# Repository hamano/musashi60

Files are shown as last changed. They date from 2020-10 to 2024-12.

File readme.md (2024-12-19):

# Musashi60 - Open Hardware Keyboard

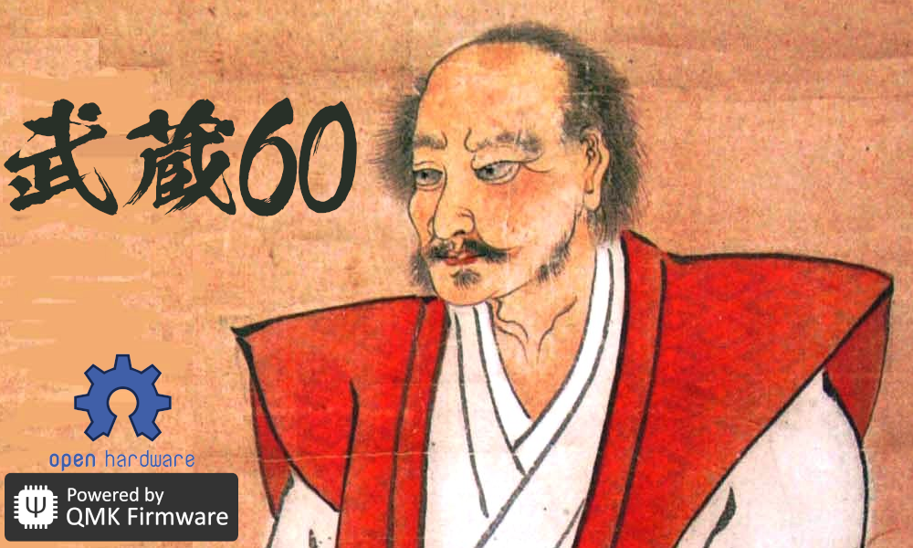
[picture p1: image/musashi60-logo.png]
musashi60-logo


## Overview

Musashi60 is open-hardware splitted keyboard.

* Keys: 60
* Layout: Ergonomic column-staggered
* All parts are available to procured or make yourself. see [parts](#parts-list).
* Keyboard Maintainer: [HAMANO Tsukasa](https://github.com/hamano)
* Hardware Supported: The PCBs, controllers supported
* Hardware Availability: Links to where you can find this hardware

Make example for this keyboard (after setting up your build environment):

    make musashi60:default

See the [build environment setup](https://docs.qmk.fm/#/getting_started_build_tools) and the [make instructions](https://docs.qmk.fm/#/getting_started_make_guide) for more information. Brand new to QMK? Start with our [Complete Newbs Guide](https://docs.qmk.fm/#/newbs).

## Gallery

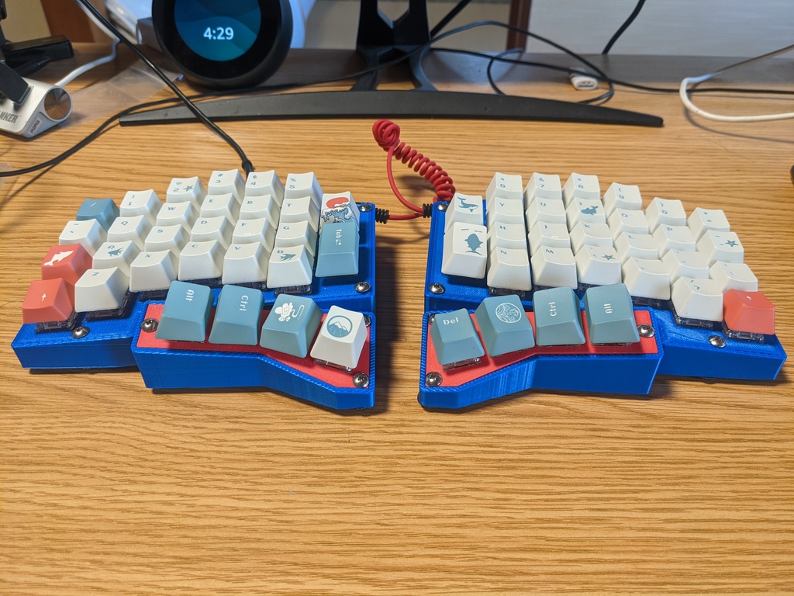
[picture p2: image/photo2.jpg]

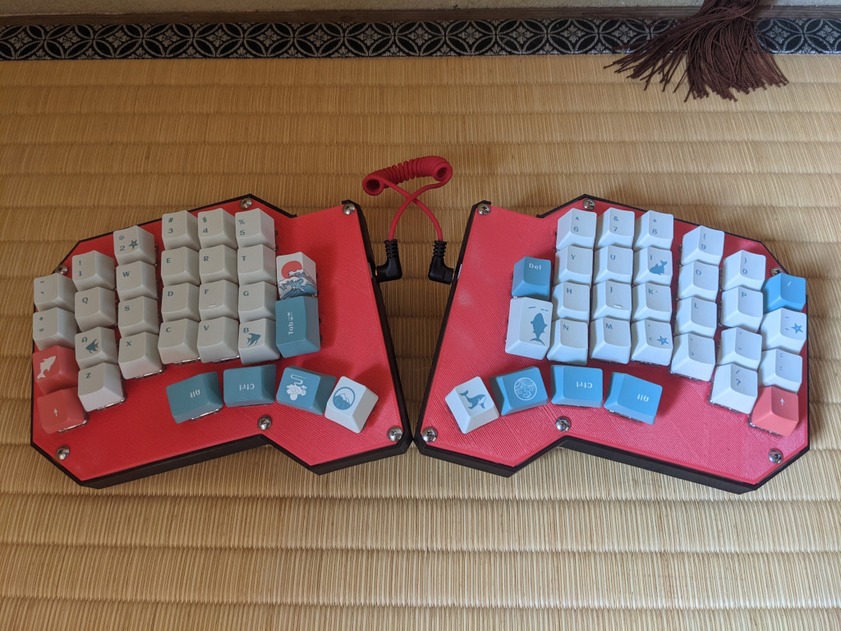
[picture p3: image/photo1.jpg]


## Parts list

- RP2024
- PCB
- case
- plate
- screw

## Build guide

Comming soon...

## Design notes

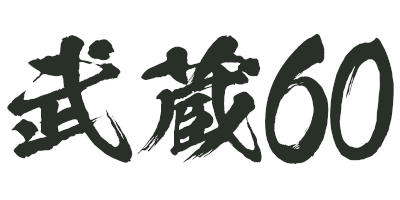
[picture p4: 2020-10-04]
image/musashi60-silk.png

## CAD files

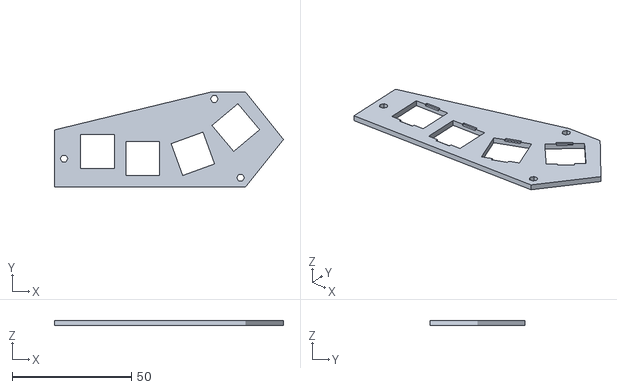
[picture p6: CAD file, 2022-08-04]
case/revG/thumb_plate.stl
96.0 x 40.0 x 2.00

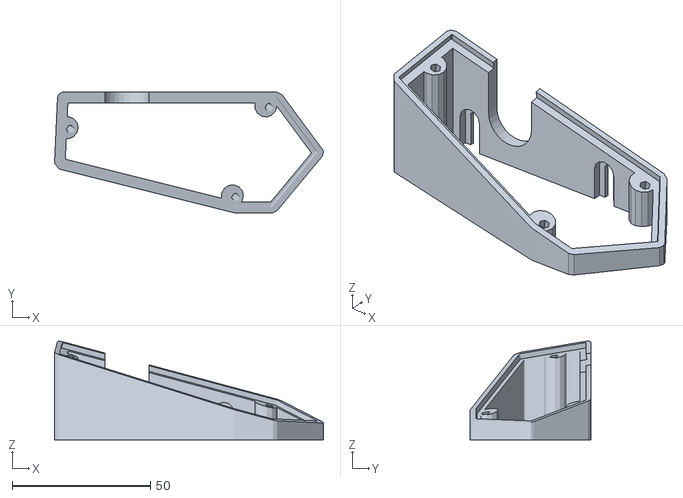
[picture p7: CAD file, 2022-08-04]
case/revG/thumb_case.stl
97.3 x 43.7 x 35.8

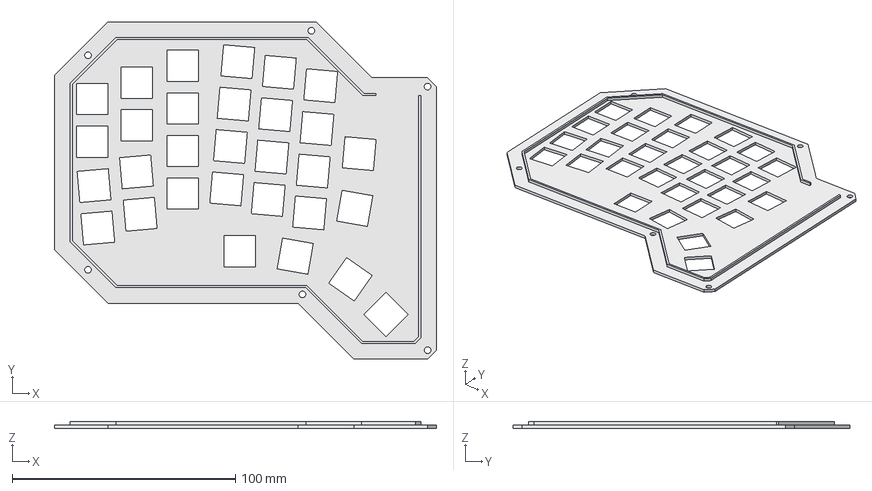
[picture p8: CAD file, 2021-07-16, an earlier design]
case/revC/revC.FCStd
171.0 x 151.0 x 3.00 mm

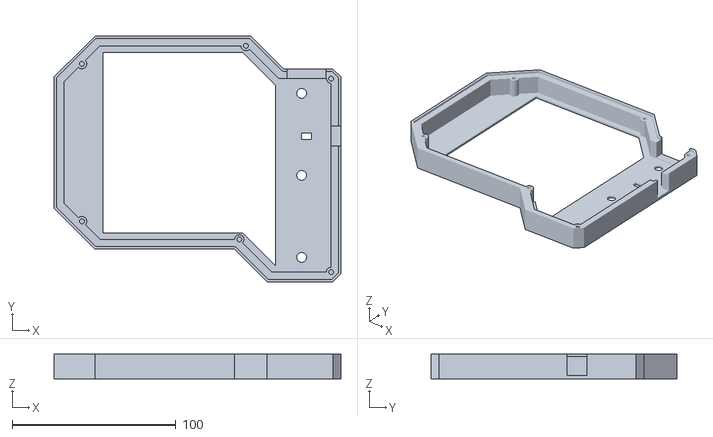
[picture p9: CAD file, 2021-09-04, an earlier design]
case/revD/revD-case5.stl
175.0 x 150.0 x 15.0

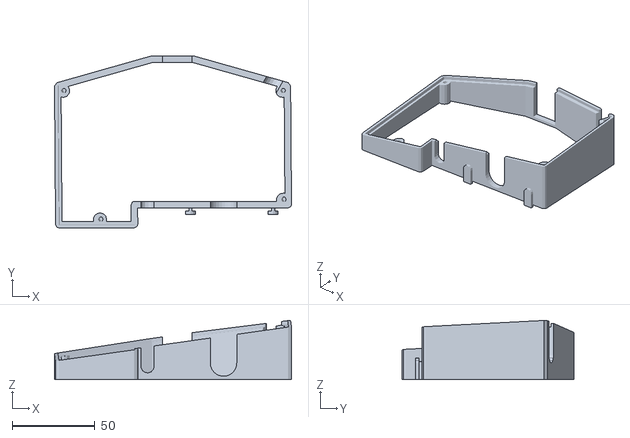
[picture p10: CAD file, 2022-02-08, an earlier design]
case/revE/finger_case.stl
143.4 x 104.0 x 35.8

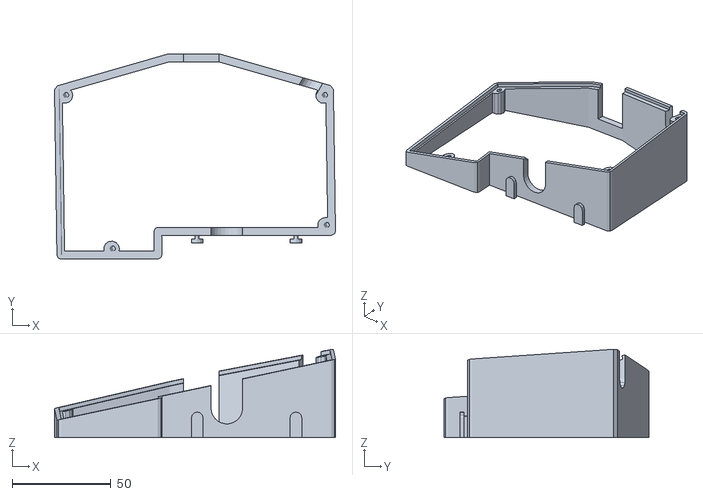
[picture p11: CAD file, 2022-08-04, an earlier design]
case/revF/finger_case.stl
142.3 x 103.9 x 44.8

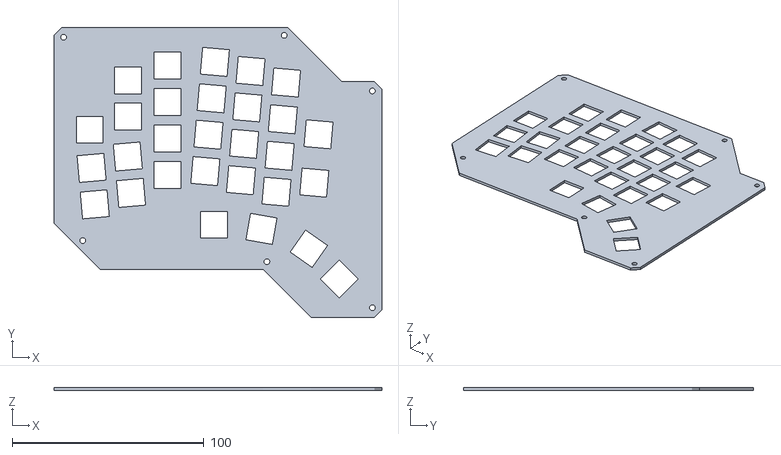
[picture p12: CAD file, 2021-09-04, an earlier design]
case/revB/revB-plate5.stl
171.0 x 151.0 x 1.50

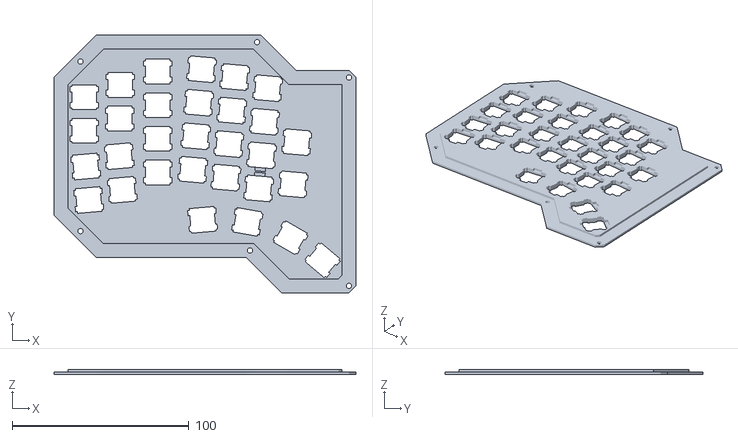
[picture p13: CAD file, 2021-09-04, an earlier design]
case/revD/revD-plate7.stl
171.0 x 146.0 x 3.00

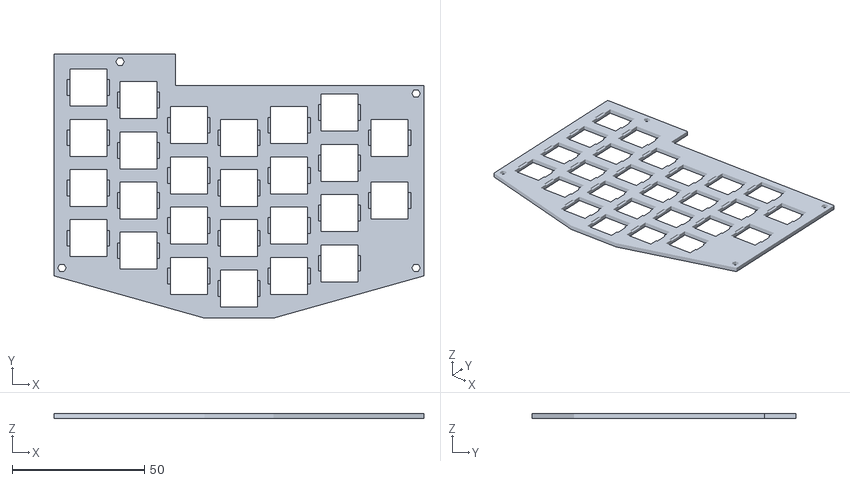
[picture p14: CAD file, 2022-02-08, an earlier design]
case/revE/finger_plate.stl
140.0 x 100.0 x 2.00

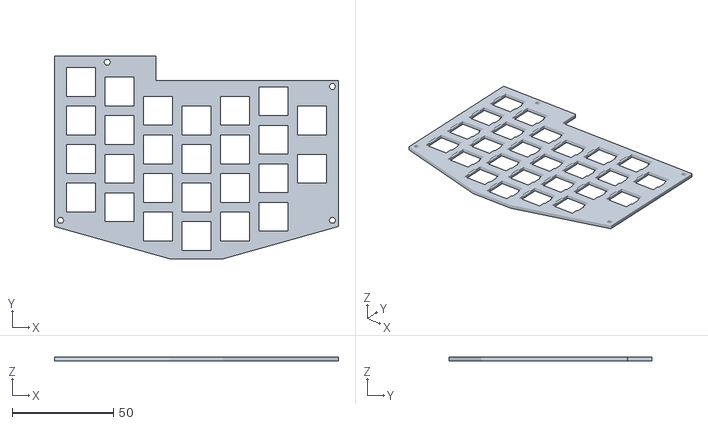
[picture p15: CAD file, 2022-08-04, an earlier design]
case/revF/finger_plate.stl
140.0 x 100.0 x 2.00

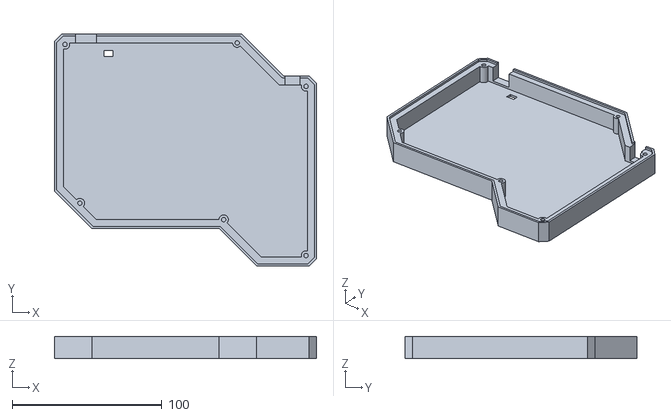
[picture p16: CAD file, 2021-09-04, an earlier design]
case/revB/revB-case-v7.stl
175.0 x 155.0 x 15.0

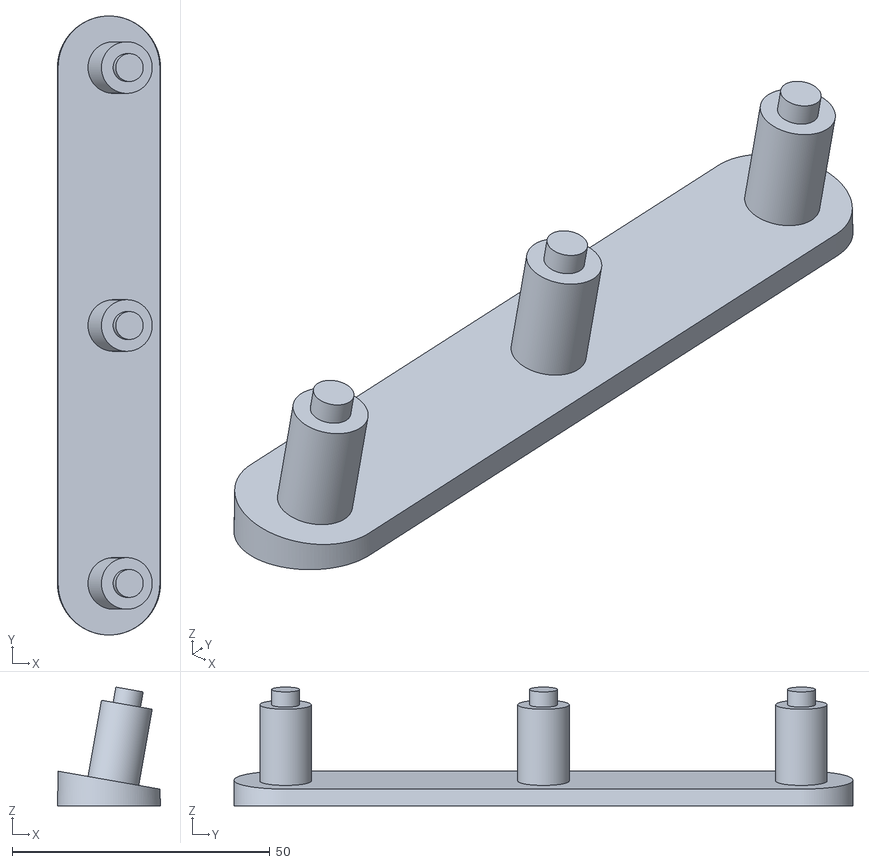
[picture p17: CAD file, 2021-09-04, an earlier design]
case/revD/revD-tilt5.stl
20.0 x 120.0 x 23.0

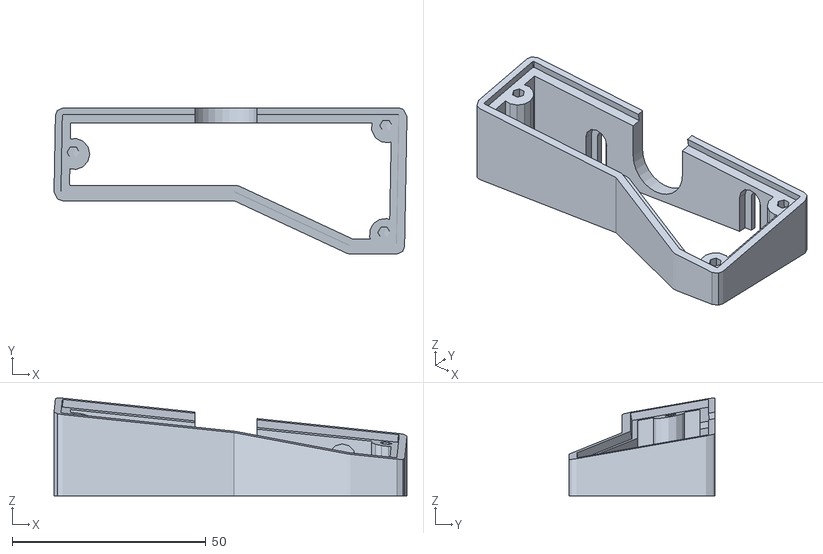
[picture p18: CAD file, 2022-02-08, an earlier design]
case/revE/thumb_case.stl
91.1 x 37.8 x 25.2

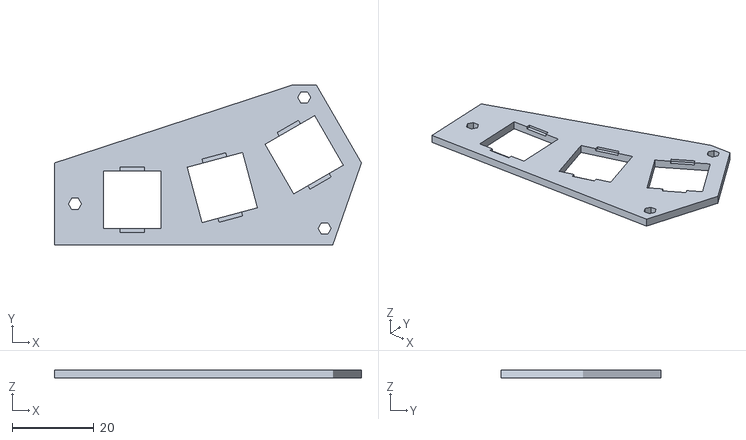
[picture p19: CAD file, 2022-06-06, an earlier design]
case/revF/thumb_plate.stl
75.0 x 39.0 x 2.00

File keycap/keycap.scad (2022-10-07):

cls = 0.2;

module cap_outer() {
    //linear_extrude(height=8, scale=0.7) {
    linear_extrude(height=8, scale=0.7) {
        offset(2, $fs=0.1) {
            square([15,15], center=true);
        }
    }
}

module cap_hole() {
    linear_extrude(height=5, scale=0.7) {
        offset(0, $fs=0.1) {
            square([15,15], center=true);
        }
    }
}

module stem_pole() {
    cylinder(d = 6, h = 10);
}

module stem_hole() {
    linear_extrude(height = 10) {
        square([1+cls, 3.8+cls], center=true);
        square([3.8+cls, 1+cls], center=true);
    }
}

module stem() {
    intersection() {
        cap_outer();
        difference() {
            stem_pole();
            stem_hole();
        };
    }
}

module cap() {
    difference() {
        cap_outer();
        cap_hole();
    }
}


module keycap() {
    cap();
    stem();
}

//cap_outer();

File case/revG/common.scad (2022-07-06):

cls = 0.20;

module keyswitch_hole(x=0, y=0, a=0) {
    translate([x, y, 0]) {
        rotate([0, 0, 90+a]) {
            linear_extrude(height = 2) {
            square([14+cls, 14+cls], center = true);
            }
            linear_extrude(height = 0.6) {
                translate([-3, 7]) square([6, 1]);
            translate([-3, -8]) square([6, 1]);
            }
        }
    }
}

keyswitch_hole();

module joint_male_face() {
    translate([-1, 0])
    square([2,4]);
    translate([-3, 2])
    square([6,2]);
}

module joint_male(pos=[0,0]) {
    translate(pos){
      rotate([0,0,180]){
        linear_extrude(height=10)
        joint_male_face();
        
        translate([0,2,10])
        rotate([-90,0,0])
        linear_extrude(height=2)
        circle(3, $fn=12);
        
        translate([0,0,10])
        rotate([-90,0,0])
        linear_extrude(height=2)
        circle(1, $fn=12);
      }
    }
}

module joint_female(pos=[0,0]) {
    delta = 0.6;
    translate(pos){
      rotate([0,0,180]){
        linear_extrude(height=10)
        offset(delta=delta)
        joint_male_face();
        
        translate([0,1.6,10])
        rotate([-90,0,0])
        linear_extrude(height=2.8)
        offset(delta=delta)
        circle(3, $fn=12);

        translate([0,-0.4,10])
        rotate([-90,0,0])
        linear_extrude(height=2.8)
        offset(delta=delta)
        circle(1, $fn=12);
      }
    }
}


joint_male([20, 0]);
joint_female([30, 0]);

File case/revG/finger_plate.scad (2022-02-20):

use <finger.scad>;

translate([0,-10])
rotate([180,0,0])
finger_plate();

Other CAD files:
case/revB/revB-plate.FCStd
case/revB/revB-hexbottom.FCStd
case/revD/revD.FCStd
case/revE/thumb_plate.stl
case/revG/main.scad
case/revB/revB-case-v6.stl
case/revB/revB-plate.dxf
case/revB/revB.FCStd
case/revE/common.scad
case/revE/finger.scad
case/revE/thumb.scad
case/revF/finger.scad
case/revF/thumb_case.stl
case/revG/main_case.scad
case/revG/main_plate.scad
case/revG/thumb.scad
case/revG/thumb_case.scad
case/revG/thumb_plate.scad
case/revG/unit_case.scad

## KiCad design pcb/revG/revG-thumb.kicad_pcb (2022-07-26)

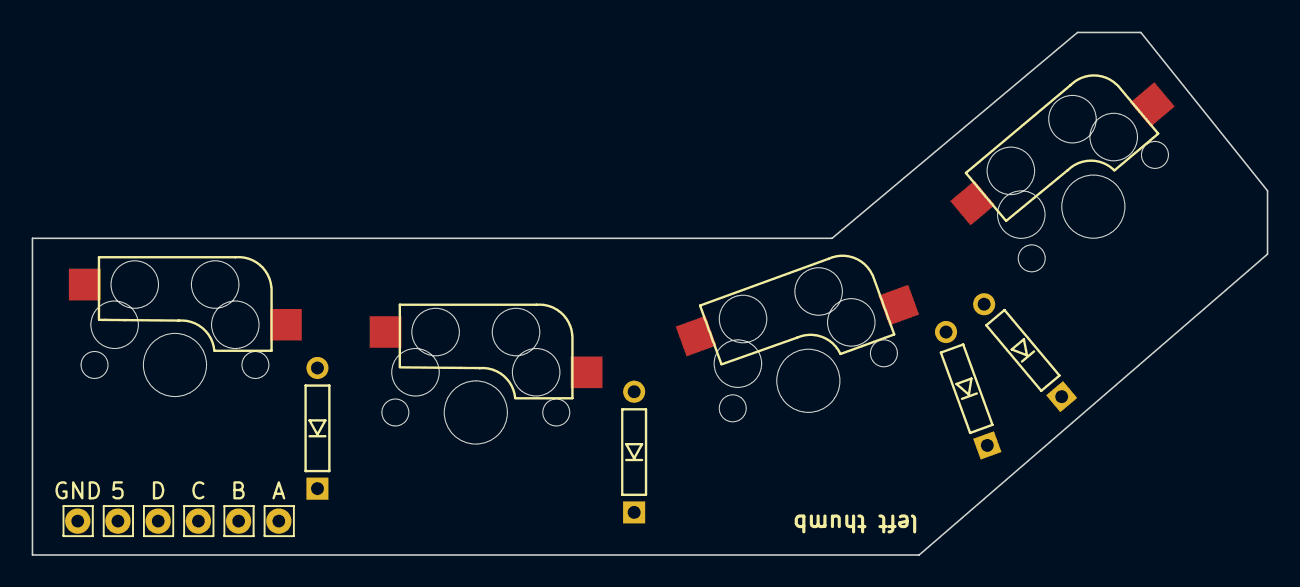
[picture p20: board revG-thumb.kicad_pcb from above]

Board: 2 copper layers, 78.0 x 33.0 mm, 14 parts (0 on the bottom side), 9 nets, no tracks yet.

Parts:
D_LA5: D_A5; D_TH_Reversible
D_LB5: D_B5; D_TH_Reversible
D_LC5: D_C5; D_TH_Reversible
D_LD5: D_D5; D_TH_Reversible
H_L5: 5; Pin_D0.8mm
H_LA1: A; Pin_D0.8mm
H_LB1: B; Pin_D0.8mm
H_LC1: C; Pin_D0.8mm
H_LD5: D; Pin_D0.8mm
H_LGND1: GND; Pin_D0.8mm
SW_LA5: SW_PUSH-foostan; CherryMX_Hotswap_Reversible
SW_LB5: SW_PUSH-foostan; CherryMX_Hotswap_Reversible
SW_LC5: SW_PUSH-foostan; CherryMX_Hotswap_Reversible
SW_LD5: SW_PUSH-foostan; CherryMX_Hotswap_Reversible

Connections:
unnamed: D_LA5.1, D_LB5.1, D_LC5.1, D_LD5.1, H_L5.1
unnamed: D_LA5.2, SW_LA5.1
unnamed: D_LB5.2, SW_LB5.1
unnamed: D_LC5.2, SW_LC5.1
unnamed: D_LD5.2, SW_LD5.1
unnamed: H_LA1.1, SW_LA5.2
unnamed: H_LB1.1, SW_LB5.2
unnamed: H_LC1.1, SW_LC5.2
unnamed: H_LD5.1, SW_LD5.2

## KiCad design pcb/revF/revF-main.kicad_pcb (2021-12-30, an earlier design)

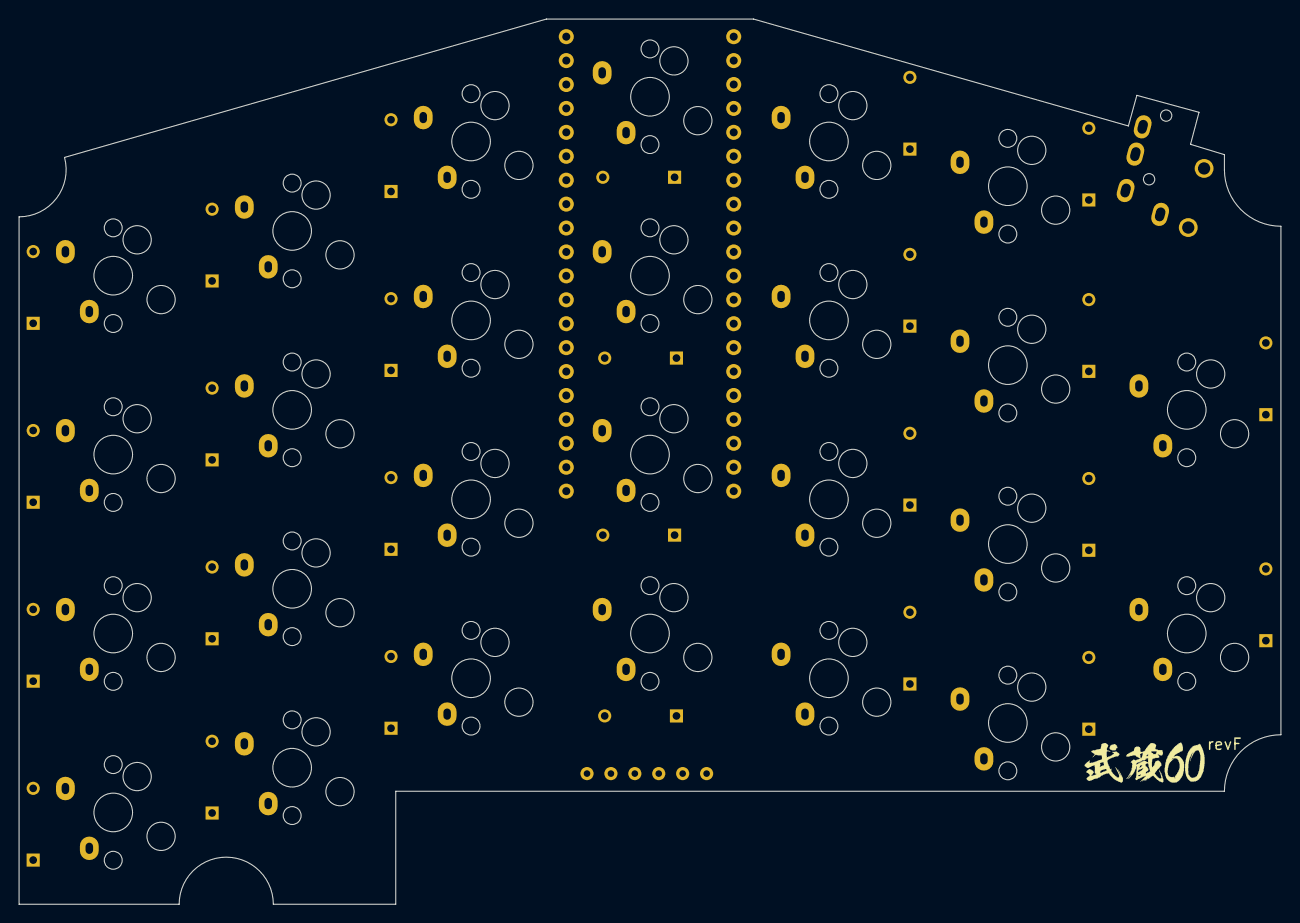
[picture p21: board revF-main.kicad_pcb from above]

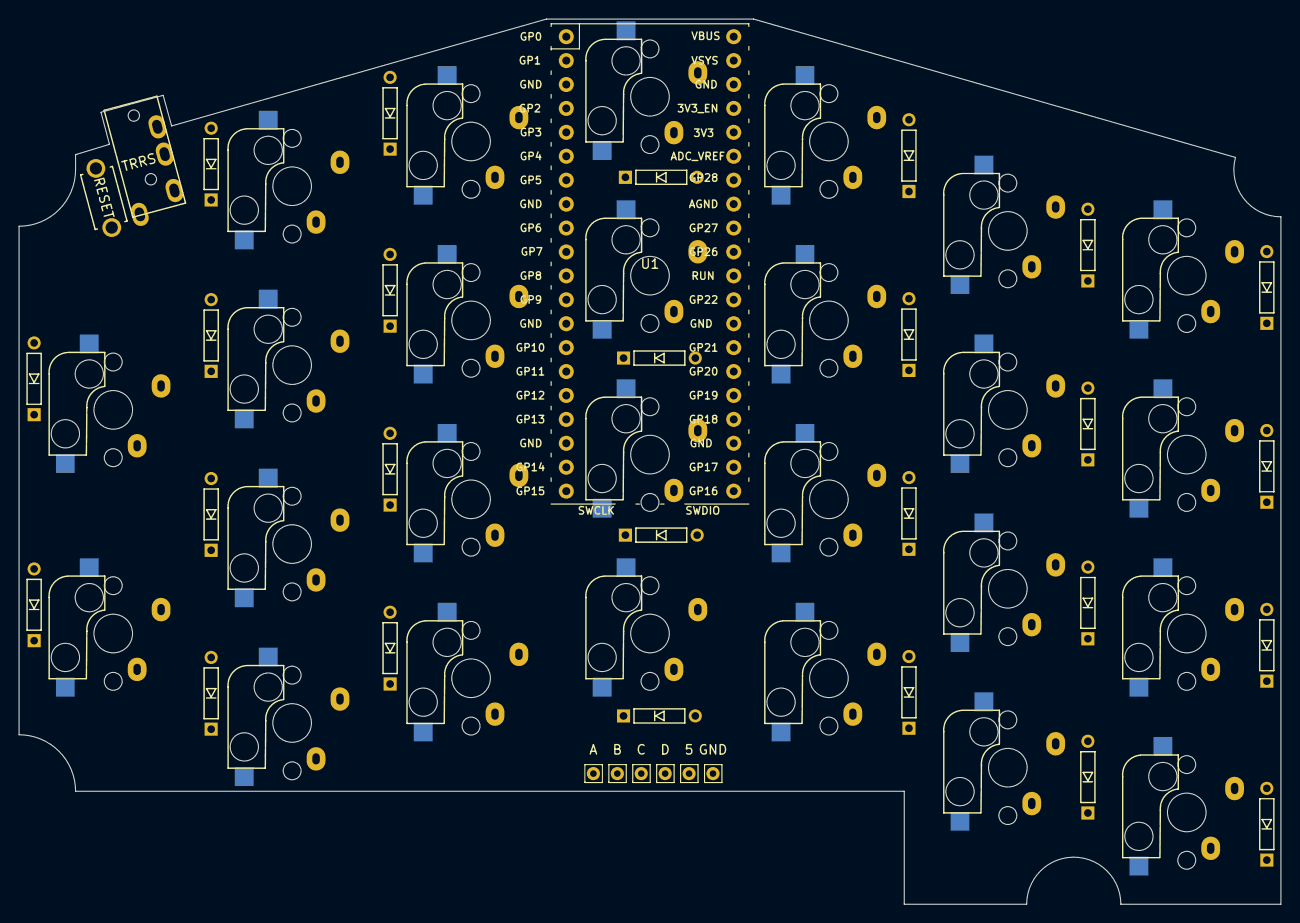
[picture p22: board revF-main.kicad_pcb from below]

Board: 2 copper layers, 134.0 x 94.0 mm, 61 parts (35 on the bottom side), 42 nets, no tracks yet.

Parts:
D_A2, D_A3: D; D_TH
D_B1, D_B2, D_B3, D_B4: D; D_TH
D_C1, D_C2, D_C3, D_C4: D; D_TH
D_D1, D_D2, D_D3, D_D4: D; D_TH
D_E1, D_E2, D_E3, D_E4: D; D_TH
D_F1, D_F2, D_F3, D_F4: D; D_TH
D_G1, D_G2, D_G3, D_G4: D; D_TH
H_5: 5; Pin_D0.7mm
H_A1: A; Pin_D0.7mm
H_B1: B; Pin_D0.7mm
H_C1: C; Pin_D0.7mm
H_D1: D; Pin_D0.7mm
H_GND1: GND; Pin_D0.7mm
J1: MJ-4PP-9
SW_A2, SW_A3: SW_PUSH; CherryMX_Direct_Hotswap
SW_B1, SW_B2, SW_B3, SW_B4: SW_PUSH; CherryMX_Direct_Hotswap
SW_C1, SW_C2, SW_C3, SW_C4: SW_PUSH; CherryMX_Direct_Hotswap
SW_D1, SW_D2, SW_D3, SW_D4: SW_PUSH; CherryMX_Direct_Hotswap
SW_E1, SW_E2, SW_E3, SW_E4: SW_PUSH; CherryMX_Direct_Hotswap
SW_F1, SW_F2, SW_F3, SW_F4: SW_PUSH; CherryMX_Direct_Hotswap
SW_G1, SW_G2, SW_G3, SW_G4: SW_PUSH; CherryMX_Direct_Hotswap
SW_RST1: SW_DIP_x01; ResetSW
U1: Pico; RPi_Pico_TH

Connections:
GND: H_GND1.1, J1.C, SW_RST1.1, U1.3, U1.8, U1.13, U1.18, U1.23, U1.28, U1.38
unnamed: D_A2.2, SW_A2.2
unnamed: D_A3.2, SW_A3.2
unnamed: D_B1.2, SW_B1.2
unnamed: D_B2.2, SW_B2.2
unnamed: D_B3.2, SW_B3.2
unnamed: D_B4.2, SW_B4.2
unnamed: D_C1.2, SW_C1.2
unnamed: D_C2.2, SW_C2.2
unnamed: D_C3.2, SW_C3.2
unnamed: D_C4.2, SW_C4.2
unnamed: D_D1.2, SW_D1.2
unnamed: D_D2.2, SW_D2.2
unnamed: D_D3.2, SW_D3.2
unnamed: D_D4.2, SW_D4.2
unnamed: D_E1.2, SW_E1.2
unnamed: D_E2.2, SW_E2.2
unnamed: D_E3.2, SW_E3.2
unnamed: D_E4.2, SW_E4.2
unnamed: D_F1.2, SW_F1.2
unnamed: D_F2.2, SW_F2.2
unnamed: D_F3.2, SW_F3.2
unnamed: D_F4.2, SW_F4.2
unnamed: D_G1.2, SW_G1.2
unnamed: D_G2.2, SW_G2.2
unnamed: D_G3.2, SW_G3.2
unnamed: D_G4.2, SW_G4.2
RUN: SW_RST1.2, U1.30
colA: H_A1.1, U1.21
colB: H_B1.1, U1.22
colC: H_C1.1, U1.24
colD: H_D1.1, U1.25
colE: SW_E4.1, U1.26
colF: SW_F4.1, U1.27
colG: SW_G4.1, U1.29
data: J1.B, U1.4
hand: J1.D, U1.5, U1.39
row1: D_B1.1, D_C1.1, D_D1.1, D_E1.1, D_F1.1, D_G1.1, U1.14
row2: D_A2.1, D_B2.1, D_C2.1, D_D2.1, D_E2.1, D_F2.1, D_G2.1, U1.15
row3: D_A3.1, D_B3.1, D_C3.1, D_D3.1, D_E3.1, D_F3.1, D_G3.1, U1.16
row4: D_B4.1, D_C4.1, D_D4.1, D_E4.1, D_F4.1, D_G4.1, U1.17
row5: H_5.1, U1.19

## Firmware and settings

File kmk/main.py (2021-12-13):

import board
import digitalio

import pwmio
import time
from kb import KMKKeyboard

from kmk.keys import KC
from kmk.modules.layers import Layers
from kmk.modules.modtap import ModTap
from kmk.modules.split import Split, SplitSide, SplitType

led = digitalio.DigitalInOut(board.GP25)
led.direction = digitalio.Direction.OUTPUT
led.value = True

hand_pin = digitalio.DigitalInOut(board.GP28)
hand_pin.direction = digitalio.Direction.INPUT
is_left = hand_pin.value

keyboard = KMKKeyboard()
keyboard.tap_time = 100
keyboard.debug_enabled = True

layers_ext = Layers()
modtap_ext = ModTap()

if is_left:
    print('left side')
    split_side = SplitSide.LEFT
    data_pin = board.GP5
    data_pin2 = None
else:
    print('right side')
    split_side = SplitSide.RIGHT
    data_pin = board.GP4
    data_pin2 = None

split = Split(
    split_side=split_side,
    split_type=SplitType.UART,
#    split_flip=True,
    data_pin=data_pin,
    data_pin2=data_pin2,
#    target_left=True,
#    split_target_left=True,
    debug_enabled=True
)

keyboard.modules = [layers_ext, modtap_ext, split]

LOWER = KC.MO(1)
RAISE = KC.MO(2)
ADJUST = KC.MO(3)
MT_LALT = KC.MT(KC.MHEN, KC.LALT)
MT_RALT = KC.MT(KC.HENK, KC.LALT)
RESET = KC.RESET

keyboard.keymap = [
    [  # QWERTY
        # ------+--------+--------+--------+--------+--------+                 +--------+--------+--------+--------+--------+--------+
        KC.BSLS, KC.N1,   KC.N2,   KC.N3,   KC.N4,   KC.N5,                     KC.N6,   KC.N7,   KC.N8,   KC.N9,   KC.N0,   KC.EQL, \
        # ------+--------+--------+--------+--------+--------+--------+--------+--------+--------+--------+--------+--------+--------+
        KC.GRV,  KC.Q,    KC.W,    KC.E,    KC.R,    KC.T,    KC.ESC,  KC.DEL,  KC.Y,    KC.U,    KC.I,    KC.O,    KC.P,    KC.MINS,\
        # ------+--------+--------+--------+--------+--------+--------+--------+--------+--------+--------+--------+--------+--------+
        KC.LGUI, KC.A,    KC.S,    KC.D,    KC.F,    KC.G,    KC.TAB,  KC.BSPC, KC.H,    KC.J,    KC.K,    KC.L,    KC.SCLN, KC.QUOT,\
        # ------+--------+--------+--------+--------+--------+--------+--------+--------+--------+--------+--------+--------+--------+
        KC.LSFT, KC.Z,    KC.X,    KC.C,    KC.V,    KC.B,                      KC.N,    KC.M,    KC.COMM, KC.DOT,  KC.SLSH, KC.MINS,\
        # ------+--------+--------+--------+--------+--------+--------+--------+--------+--------+--------+--------+--------+--------+
                                   MT_LALT, KC.LCTL, KC.SPC,  KC.SPC,  KC.SPC,  KC.ENT,  KC.RCTL, MT_RALT
        # ------+--------+--------+--------+--------+--------+--------+--------+--------+--------+--------+--------+--------+--------+
    ]
]

if __name__ == '__main__':
    keyboard.go()

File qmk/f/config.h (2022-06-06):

/*
Copyright 2021 HAMANO Tsukasa

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
You should have received a copy of the GNU General Public License
along with this program.  If not, see <http://www.gnu.org/licenses/>.
*/

#pragma once

#include "config_common.h"

/* USB Device descriptor parameter */
#define VENDOR_ID 0xFEED
#define PRODUCT_ID 0x0634
#define DEVICE_VER 0x0001
#define MANUFACTURER @hamano
#define PRODUCT Musashi60
#define DESCRIPTION A custom keyboard

/* key matrix size */
#define MATRIX_ROWS 5 * 2
#define MATRIX_COLS 7

/*
 * Keyboard Matrix Assignments
 *
 * Change this to how you wired your keyboard
 * COLS: AVR pins used for columns, left to right
 * ROWS: AVR pins used for rows, top to bottom
 * DIODE_DIRECTION: COL2ROW = COL = Anode (+), ROW = Cathode (-, marked on diode)
 *                  ROW2COL = ROW = Anode (+), COL = Cathode (-, marked on diode)
 *
 */
#define MATRIX_ROW_PINS { GP10, GP11, GP12, GP13, GP14 }
#define MATRIX_COL_PINS { GP16, GP17, GP18, GP19, GP20, GP21, GP22 }
#define UNUSED_PINS

/* COL2ROW, ROW2COL */
#define DIODE_DIRECTION COL2ROW

/*
 * Split Keyboard specific options, make sure you have 'SPLIT_KEYBOARD = yes' in your rules.mk, and define SOFT_SERIAL_PIN.
 */
//#define SOFT_SERIAL_PIN GP0
#define SOFT_SERIAL_PIN GP3
#define SPLIT_HAND_PIN GP28
//#define SERIAL_USART_FULL_DUPLEX
//#define SERIAL_USART_TX_PIN GP0
//#define SERIAL_USART_RX_PIN GP1

//#define MASTER_LEFT
#define DEBUG_MATRIX_SCAN_RATE
//#define DEBUG_ACTION

// #define BACKLIGHT_PIN B7
// #define BACKLIGHT_BREATHING
// #define BACKLIGHT_LEVELS 3

// #define RGB_DI_PIN E2
// #ifdef RGB_DI_PIN
//   #define RGBLED_NUM 16
//   #define RGBLIGHT_HUE_STEP 8
//   #define RGBLIGHT_SAT_STEP 8
//   #define RGBLIGHT_VAL_STEP 8
//   #define RGBLIGHT_LIMIT_VAL 255 /* The maximum brightness level */
//   #define RGBLIGHT_SLEEP  /* If defined, the RGB lighting will be switched off when the host goes to sleep */
// /*== all animations enable ==*/
//   #define RGBLIGHT_ANIMATIONS
// /*== or choose animations ==*/
//   #define RGBLIGHT_EFFECT_BREATHING
//   #define RGBLIGHT_EFFECT_RAINBOW_MOOD
//   #define RGBLIGHT_EFFECT_RAINBOW_SWIRL
//   #define RGBLIGHT_EFFECT_SNAKE
//   #define RGBLIGHT_EFFECT_KNIGHT
//   #define RGBLIGHT_EFFECT_CHRISTMAS
//   #define RGBLIGHT_EFFECT_STATIC_GRADIENT
//   #define RGBLIGHT_EFFECT_RGB_TEST
//   #define RGBLIGHT_EFFECT_ALTERNATING
// /*== customize breathing effect ==*/
//   /*==== (DEFAULT) use fixed table instead of exp() and sin() ====*/
//   #define RGBLIGHT_BREATHE_TABLE_SIZE 256      // 256(default) or 128 or 64
//   /*==== use exp() and sin() ====*/
//   #define RGBLIGHT_EFFECT_BREATHE_CENTER 1.85  // 1 to 2.7
//   #define RGBLIGHT_EFFECT_BREATHE_MAX    255   // 0 to 255
// #endif

/* Debounce reduces chatter (unintended double-presses) - set 0 if debouncing is not needed */
#define DEBOUNCE 5

/* define if matrix has ghost (lacks anti-ghosting diodes) */
//#define MATRIX_HAS_GHOST

/* Mechanical locking support. Use KC_LCAP, KC_LNUM or KC_LSCR instead in keymap */
#define LOCKING_SUPPORT_ENABLE
/* Locking resynchronize hack */
#define LOCKING_RESYNC_ENABLE

/* If defined, GRAVE_ESC will always act as ESC when CTRL is held.
 * This is userful for the Windows task manager shortcut (ctrl+shift+esc).
 */
// #define GRAVE_ESC_CTRL_OVERRIDE

/*
 * Force NKRO
 *
 * Force NKRO (nKey Rollover) to be enabled by default, regardless of the saved
 * state in the bootmagic EEPROM settings. (Note that NKRO must be enabled in the
 * makefile for this to work.)
 *
 * If forced on, NKRO can be disabled via magic key (default = LShift+RShift+N)
 * until the next keyboard reset.
 *
 * NKRO may prevent your keystrokes from being detected in the BIOS, but it is
 * fully operational during normal computer usage.
 *
 * For a less heavy-handed approach, enable NKRO via magic key (LShift+RShift+N)
 * or via bootmagic (hold SPACE+N while plugging in the keyboard). Once set by
 * bootmagic, NKRO mode will always be enabled until it is toggled again during a
 * power-up.
 *
 */
//#define FORCE_NKRO

/*
 * Magic Key Options
 *
 * Magic keys are hotkey commands that allow control over firmware functions of
 * the keyboard. They are best used in combination with the HID Listen program,
 * found here: https://www.pjrc.com/teensy/hid_listen.html
 *
 * The options below allow the magic key functionality to be changed. This is
 * useful if your keyboard/keypad is missing keys and you want magic key support.
 *
 */

/* key combination for magic key command */
/* defined by default; to change, uncomment and set to the combination you want */
// #define IS_COMMAND() (get_mods() == MOD_MASK_SHIFT)

/* control how magic key switches layers */
//#define MAGIC_KEY_SWITCH_LAYER_WITH_FKEYS  true
//#define MAGIC_KEY_SWITCH_LAYER_WITH_NKEYS  true
//#define MAGIC_KEY_SWITCH_LAYER_WITH_CUSTOM false
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

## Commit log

2020-09-23 add pcb
    [musashi60.kicad_pcb, musashi60.sch]
2020-09-23 add wired pcb
    [musashi60_wired.kicad_pcb]
2020-10-02 fix q and p layout
    [musashi60.kicad_pcb]
2020-10-02 remove mounting hole
    [musashi60.kicad_pcb]
2020-10-02 fix colG and colH
    [musashi60.kicad_pcb]
2020-10-03 add jumper for left hand
    [musashi60.sch]
2020-10-03 update pcb
    [musashi60.kicad_pcb]
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2020-10-04 update wired pcb
    [musashi60_wired.kicad_pcb]
2020-10-06 change clearance 0.2 -> 0.23
    [musashi60.kicad_pcb]
2020-10-06 change edge
    [musashi60.kicad_pcb]
2020-12-07 remove musashi60.sch
    [musashi60.sch]
2020-12-11 Revert "remove musashi60.sch"
    This reverts commit e95140cd4166689b95f370a70f5812e26694df12.
    [musashi60.sch]
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2021-01-12 update circut
    [musashi60.sch]
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2021-02-05 update circut for rev8
    [musashi60.sch]
2021-02-05 update pcb for rev8
    [musashi60.kicad_pcb]
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2021-02-05 PCBの微調整
    [musashi60.kicad_pcb]
2021-02-12 add trackpoint cap model
    [cap.FCStd]
2021-02-12 add trackpoint stl
    [cap.stl]
2021-02-15 rename pcb
    [musashi50.kicad_pcb]
2021-02-15 rename sch
    [musashi50.sch]
2021-02-15 add rev8 snapshot
    [musashi50-rev8-wired.kicad_pcb, musashi50-rev8.kicad_pcb, musashi50-rev8.sch]
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2021-03-19 remove musashi50-rev8.sch
    [musashi50-rev8.sch]
2021-03-22 update rev9
    [musashi50.sch]
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2021-03-23 add pcb rev9
    [musashi60-rev9.kicad_pcb]
2021-05-01 use Joycon_Stick_Short
    [musashi60.sch]
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2021-05-01 remove test pin
    [musashi60.sch]
2021-05-31 update scheme
    [musashi60.sch]
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2021-06-10 add musashi60-revA-wired.kicad_pcb
    [musashi60-revA-wired.kicad_pcb]
2021-06-10 update sch
    [musashi60.sch]
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2021-06-21 remove js cap
    [cap-small.FCStd, cap-small.stl]
2021-07-05 remove rev8 pcb
    [musashi50-rev8.kicad_pcb]
2021-07-05 add revB-case-v6
    [revB-case-v6.stl]
2021-07-05 remove rev9 pcb
    [musashi60-rev9.kicad_pcb]
2021-07-05 add last key
    [musashi60.sch]
2021-07-05 add revB case
    [revB.FCStd]
2021-07-08 add revB wired pcb
    [musashi60-revB-wired.kicad_pcb]
2021-07-08 add revB sch
    [musashi60-revB.sch]
2021-07-08 add revC sch
    [musashi60.sch]
2021-07-08 add revC pcb
    [musashi60-revC-wired.kicad_pcb]
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2021-07-16 add revC case
    [revC.FCStd]
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2021-07-16 add revD pcb
    [musashi60-revD.kicad_pcb]
2021-07-30 update revD pcb
    [musashi60-revD.kicad_pcb]
2021-07-30 update revD scheme
    [musashi60.sch]
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2021-08-19 update scheme for revD
    [musashi60.sch]
2021-08-19 add wired pcb for revD
    [musashi60-revD-wired.kicad_pcb]
2021-08-19 add case for revD
    [revD.FCStd]
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2021-09-04 add revD tilt
    [revD-tilt5.stl]
2021-09-04 add revB plate
    [revB-plate5.stl]
2021-09-04 rename dir
    [revB.FCStd]
2021-09-04 add revD plate
    [revD-plate7.stl]
2021-09-04 add revD case
    [revD-case5.stl]
2021-09-04 rename revC case
    [revC.FCStd]
2021-09-04 rename revB case
    [revB-case-v6.stl, revB-case-v7.stl, revB-hexbottom.FCStd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]
2021-09-04 rename revD case
    [revD-case5.stl, revD-plate7.stl, revD-tilt5.stl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]
2021-09-04 add resetsw footprint
2021-11-24 add new case
    [common.scad]
2021-11-26 rotate keyhole
    [common.scad]
2021-11-26 add hole
    [finger.scad]
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2021-11-28 rename files
    [musashi60.sch]
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2021-12-01 change dirs
    [musashi60-revD.kicad_pcb]
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2021-12-01 fix pico symbol
2021-12-01 update finger case
    [finger.scad]
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2021-12-01 update resetsw footprint
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2021-12-02 remove old pcb
    [musashi60-revA-wired.kicad_pcb]
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2021-12-02 remove olf scheme
    [musashi60-revB.sch]
2021-12-02 add revA pcb
    [musashi60-revA-wired.kicad_pcb]
2021-12-06 add revE pcb
    [revE-main.kicad_pcb, revE-main.sch]
2021-12-06 add revE right pcb
    [revE-main-right.kicad_pcb, revE-main-wired.kicad_pcb]
2021-12-06 add thumb pcb
    [revE-thumb.sch]
2021-12-07 add revB pcb
    [musashi60-revB-wired.kicad_pcb, musashi60-revB.sch]
2021-12-10 change clearance of joint
    [common.scad]
2021-12-10 update case
    [finger.scad]
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2021-12-24 update revE case
    [finger_case.stl]
2021-12-24 update revE plate
    [finger_plate.stl]
2021-12-30 add revE thumb case
    [thumb_case.stl, thumb_plate.stl]
2021-12-30 add revF sch
    [revF-main.sch]
2021-12-30 add revF pcb
    [revF-main.kicad_pcb]
2022-01-14 add revF-main-left.kicad_pcb
    [revF-main-left.kicad_pcb]
2022-02-08 update thumb case
    [thumb.scad]
2022-02-08 update thumb case stl
    [thumb_case.stl, thumb_plate.stl]
2022-02-08 update stl
    [finger_case.stl, finger_plate.stl]
2022-02-08 add revF/thumb.scad
    [thumb.scad]
2022-02-18 add revF common
    [common.scad]
2022-02-18 update revF thumb
    [thumb.scad]
2022-02-18 update revF finger
    [finger.scad]
2022-02-20 update revF finger case
    [finger.scad]
2022-02-20 update revF thumb case
    [thumb.scad]
2022-02-20 add revF case and plate
    [finger_case.scad, finger_plate.scad, thumb_case.scad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]
2022-02-22 change joint clealance
    [common.scad]
2022-04-21 update thumb
    [thumb.scad]
2022-04-23 update revE schema
    [revE-main.sch]
2022-04-23 add revF-thumb.sch
    [revF-thumb.sch]
2022-04-23 add revF-thumb.kicad_pcb
    [revF-thumb.kicad_pcb]
2022-04-23 add revF-thumb-wired.kicad_pcb
    [revF-thumb-wired.kicad_pcb]
2022-04-24 update rev8 pcb
    [musashi50-rev8-wired.kicad_pcb]
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2022-05-11 add old pcb resources
    [musashi60-js.sch]
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2022-06-19 add key hole cls
    [common.scad]
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2022-06-19 add cls to switch hole
    [common.scad]
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

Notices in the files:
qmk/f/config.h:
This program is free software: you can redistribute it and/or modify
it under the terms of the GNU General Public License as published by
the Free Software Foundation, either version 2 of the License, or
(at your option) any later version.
